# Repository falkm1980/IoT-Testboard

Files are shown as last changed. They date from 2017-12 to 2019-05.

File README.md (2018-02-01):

# IoT-Testboard
IoT-Testboard for Raspberry pi and ESP8266

In order to get the IoT-Evaluation board running you need a recent image of Raspian-Linux.
https://www.raspberrypi.org/downloads/raspbian/

Furthermore you need to install a few more libraries.

## Wiring Pi
git clone https://github.com/WiringPi/WiringPi

./build

## Adafruit_Python GPIO Library
git clone https://github.com/adafruit/Adafruit_Python_GPIO

## Adafruit ILI9341 Display Library
git clone https://github.com/adafruit/Adafruit_Python_ILI9341

## RC-Switch (Radio outlets)
git clone https://github.com/r10r/rcswitch-pi

make

## DHT 11/22 Temp/Humidity sensor
git clone https://github.com/adafruit/Adafruit_Python_DHT

## NeoPixel WS2812:
sudo apt-get update

sudo apt-get install icons

sudo apt-get install scons

sudo apt-get install swig

sudo apt-get install build-essential python-dev unzip wget 

wget https://github.com/jgarff/rpi_ws281x/archive/master.zip && unzip master.zip && cd rpi_ws281x-master && sudo scons && cd python && 
sudo python setup.py install

## optional Div. Python libs:
sudo pip install pytz (for timezone calculation)

## Optional: Node.JS latest version
sudo wget -O - https://raw.githubusercontent.com/audstanley/NodeJs-Raspberry-Pi/master/Install-Node.sh | sudo bash;
node -v;

## Mqtt ##
Install MQTT Broker: sudo apt-get install moquitto

Install MQTT Pyhon lib: pip install paho-mqtt

see also: https://www.dinotools.de/2015/04/12/mqtt-mit-python-nutzen/

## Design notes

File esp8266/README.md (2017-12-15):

# ESP8266 Module on the board

## Installation Prerequisites
Before we can start using the ESP8266 Module we need to install some prerequisites.
check out: https://learn.adafruit.com/building-and-running-micropython-on-the-esp8266/flash-firmware

or alternatively:
http://docs.micropython.org/en/latest/esp8266/esp8266/tutorial/intro.html#deploying-the-firmware

This python file is necessary to update the MicroPython firmare installed on the module.

latest firmware can be found here:
http://micropython.org/download

## Communication with the module
in order to be able to establish a connection between the ESP8266 module and the Raspberry we need a USB cable
to connect the 2 devices.

once connected you should see a new device on the Raspberry  "/dev/ttyUSB0". ttyUSB0 can also have another name.
ttyUSB0 is a vitual serial device

Install command "screen" on the Raspberry to open up a serial terminal
sudo apt-get install screen

ince installed you can use the following command:
screen /dev/ttyUSB0 115200

now you should have a terminal open that can "talk" to the ESP8266 module.
Type: 1+1 or print ("Hello world") and see what happens.

Post request with MicroPython:
https://techtutorialsx.com/2017/06/18/esp32-esp8266-micropython-http-post-requests/

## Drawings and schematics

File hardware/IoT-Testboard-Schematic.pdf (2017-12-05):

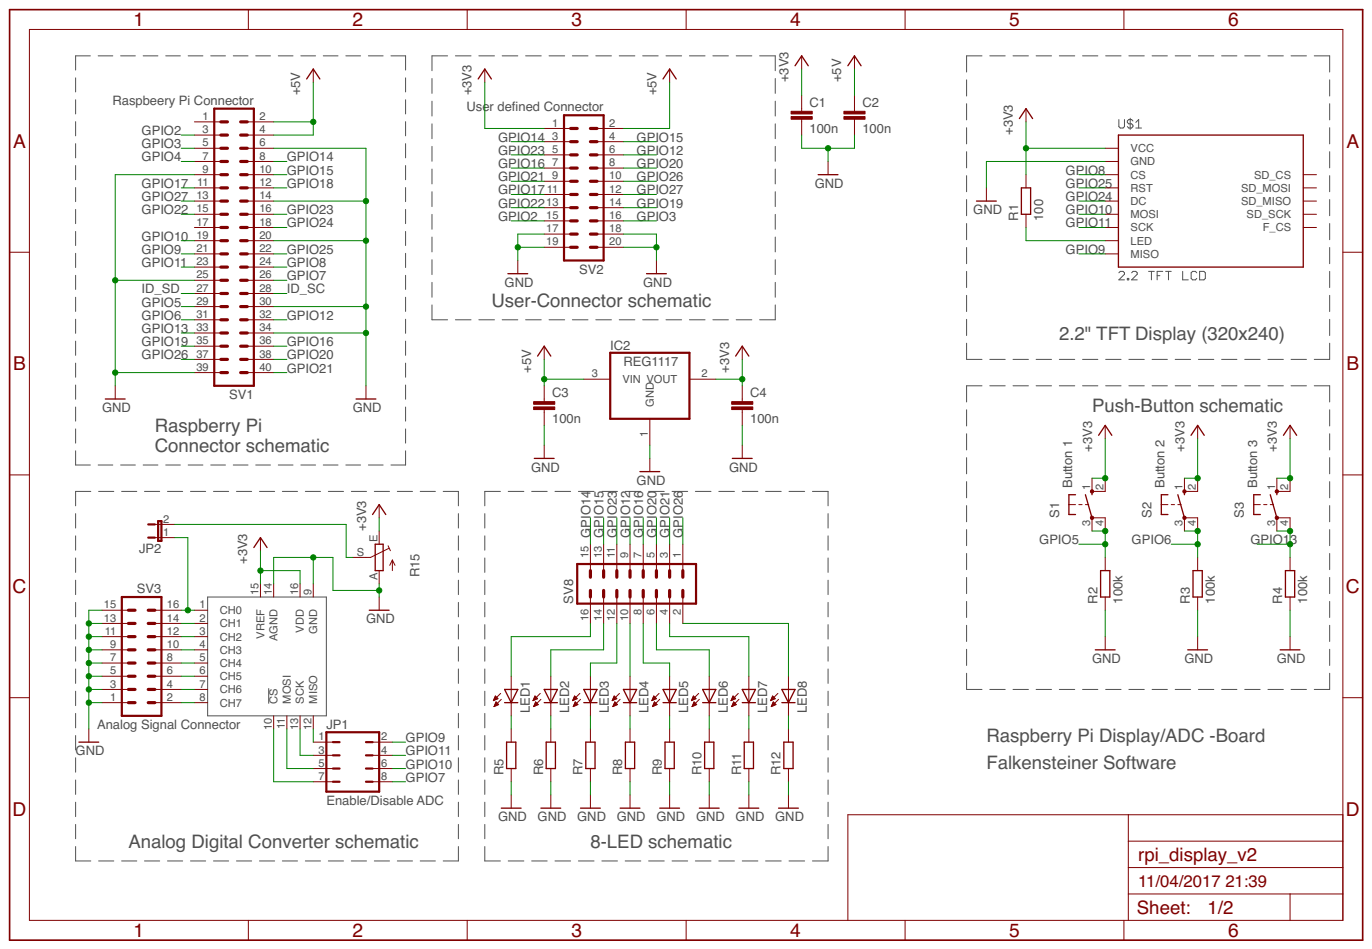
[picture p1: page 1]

Analog Signal Connector GND

Raspberry Pi Display/ADC -Board
Falkensteiner Software

GND GND GND GND

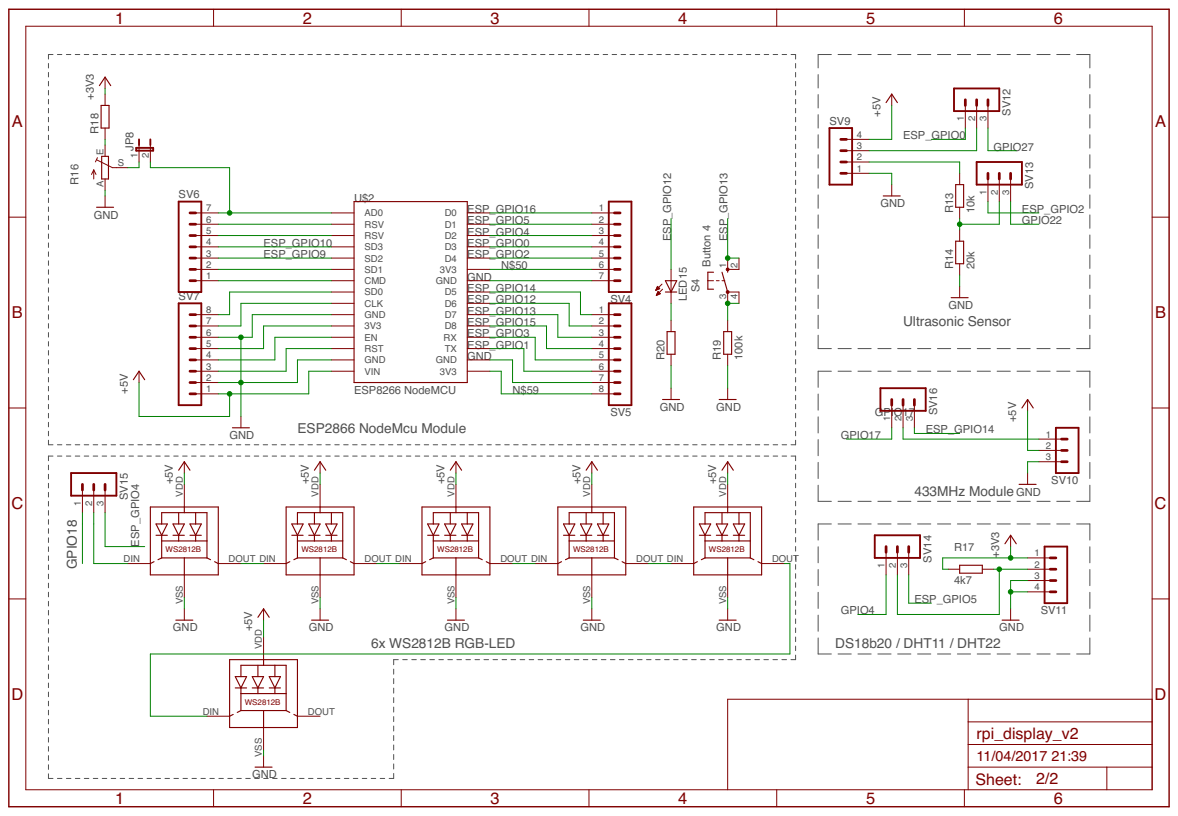
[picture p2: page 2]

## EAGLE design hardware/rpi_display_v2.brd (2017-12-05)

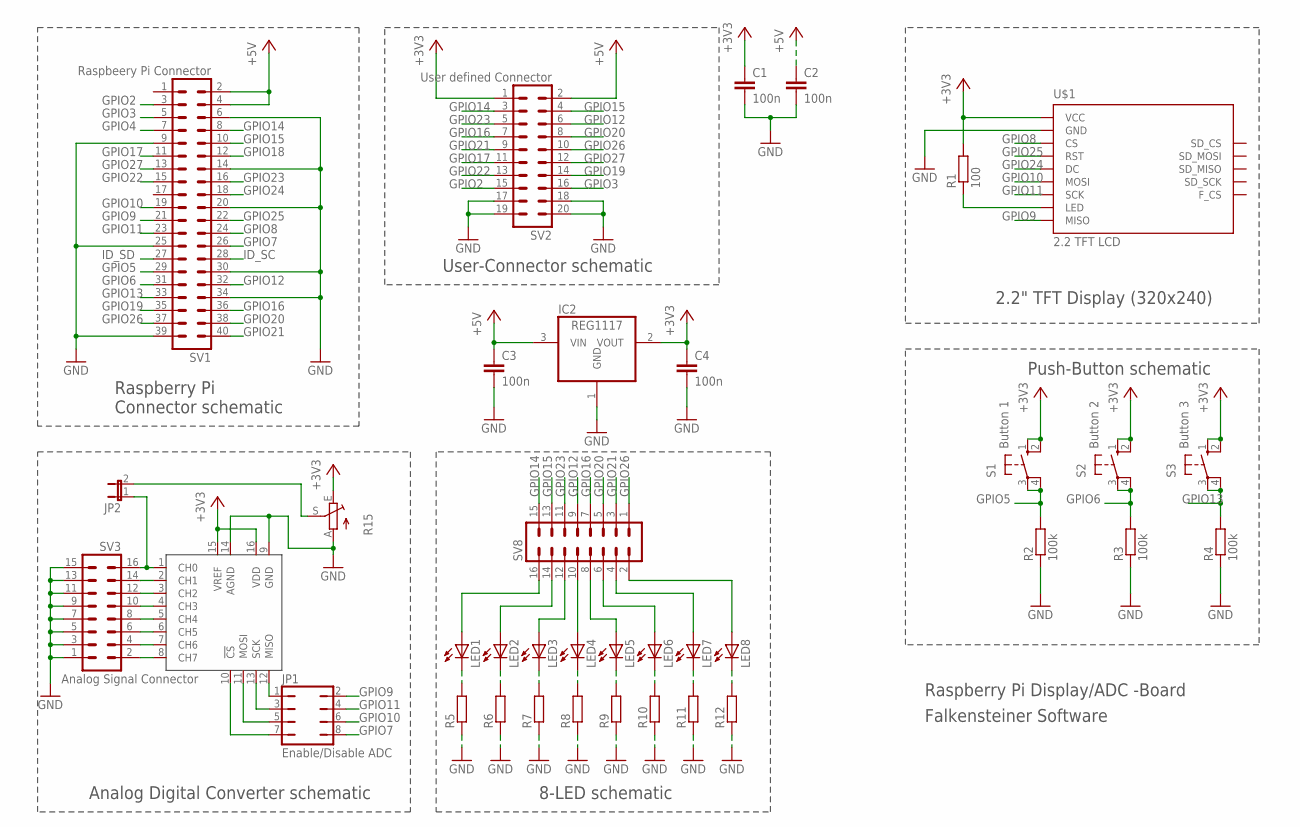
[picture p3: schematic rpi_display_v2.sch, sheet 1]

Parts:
C1, C2, C3, C4: 100n; C1206
IC1: MCP3008P; DIL16
IC2: REG1117; SOT223
JP1: Enable/Disable ADC; JP4Q
JP2: JP1E; JP1
LED1, LED2, LED3, LED4, LED5, LED6, LED7, LED8: LEDSML1206; SML1206
R1: 100; R1206
R2, R3, R4: 100k; R1206
R5, R6, R7, R8, R9, R10, R11, R12: R-EU_R1206; R1206
R15: TRIM_EU-CA6V; CA6V
S1: Button 1; B3F-10XX
S2: Button 2; B3F-10XX
S3: Button 3; B3F-10XX
SV1: Raspbeery Pi Connector; MA20-2
SV2: User defined Connector; MA10-2
SV3: Analog Signal Connector; MA08-2
SV8: MA08-2
U$1: 2.2_TFT_LCD

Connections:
+3V3: C1.1, C4.1, IC1.15 (VREF), IC1.16 (VDD), IC2.2 (VOUT), R1.2, R15.E, S1.1 (S), S1.2 (S1), S2.1 (S), S2.2 (S1), S3.1 (S), S3.2 (S1), SV2.1, U$1.VCC; also elsewhere on the board
+5V: C2.1, C3.1, IC2.3 (VIN), SV1.2, SV1.4, SV2.2; also elsewhere on the board
GND: C1.2, C2.2, C3.2, C4.2, IC1.9 (GND), IC1.14 (AGND), IC2.1 (GND), R2.1, R3.1, R4.1, R5.1, R6.1, R7.1, R8.1, R9.1, R10.1, R11.1, R12.1, R15.A, SV1.6, SV1.9, SV1.14, SV1.20, SV1.25, SV1.30, SV1.34, SV1.39, SV2.17, SV2.18, SV2.19, SV2.20, SV3.1, SV3.3, SV3.5, SV3.7, SV3.9, SV3.11, SV3.13, SV3.15, U$1.GND; also elsewhere on the board
GPIO2: SV1.3, SV2.15
GPIO3: SV1.5, SV2.16
GPIO4: SV1.7; also elsewhere on the board
GPIO5: R2.2, S1.3, S1.4 (P1), SV1.29
GPIO6: R3.2, S2.3, S2.4 (P1), SV1.31
GPIO7: JP1.8, SV1.26
GPIO8: SV1.24, U$1.CS
GPIO9: JP1.2, SV1.21, U$1.MISO
GPIO10: JP1.6, SV1.19, U$1.MOSI
GPIO11: JP1.4, SV1.23, U$1.SCK
GPIO12: SV1.32, SV2.6, SV8.9
GPIO13: R4.2, S3.3, S3.4 (P1), SV1.33
GPIO14: SV1.8, SV2.3, SV8.15
GPIO15: SV1.10, SV2.4, SV8.13
GPIO16: SV1.36, SV2.7, SV8.7
GPIO17: SV1.11, SV2.11; also elsewhere on the board
GPIO18: SV1.12; also elsewhere on the board
GPIO19: SV1.35, SV2.14
GPIO20: SV1.38, SV2.8, SV8.5
GPIO21: SV1.40, SV2.9, SV8.3
GPIO22: SV1.15, SV2.13; also elsewhere on the board
GPIO23: SV1.16, SV2.5, SV8.11
GPIO24: SV1.18, U$1.DC
GPIO25: SV1.22, U$1.RST
GPIO26: SV1.37, SV2.10, SV8.1
GPIO27: SV1.13, SV2.12; also elsewhere on the board
ID_SC: SV1.28
ID_SD: SV1.27
unnamed: R1.1, U$1.LED
unnamed: IC1.12 (MISO), JP1.1
unnamed: IC1.13 (SCK), JP1.3
unnamed: IC1.11 (MOSI), JP1.5
unnamed: IC1.10 (!CS), JP1.7
unnamed: IC1.1 (CH0), JP2.1, SV3.16
unnamed: IC1.2 (CH1), SV3.14
unnamed: IC1.3 (CH2), SV3.12
unnamed: IC1.4 (CH3), SV3.10
unnamed: IC1.5 (CH4), SV3.8
unnamed: IC1.6 (CH5), SV3.6
unnamed: IC1.7 (CH6), SV3.4
unnamed: IC1.8 (CH7), SV3.2
unnamed: LED1.A, SV8.16
unnamed: LED1.C, R5.2
unnamed: LED2.A, SV8.14
unnamed: LED2.C, R6.2
unnamed: LED3.A, SV8.12
unnamed: LED3.C, R7.2
unnamed: LED4.A, SV8.10
unnamed: LED4.C, R8.2
unnamed: LED5.A, SV8.8
unnamed: LED5.C, R9.2
unnamed: LED6.A, SV8.6
unnamed: LED6.C, R10.2
unnamed: LED7.A, SV8.4
unnamed: LED7.C, R11.2
unnamed: LED8.A, SV8.2
unnamed: LED8.C, R12.2
unnamed: JP2.2, R15.S

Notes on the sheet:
Raspberry Pi Display/ADC -Board
Falkensteiner Software
Push-Button schematic
User-Connector schematic
Raspberry Pi Connector schematic
Analog Digital Converter schematic
8-LED schematic
2.2" TFT Display (320x240)

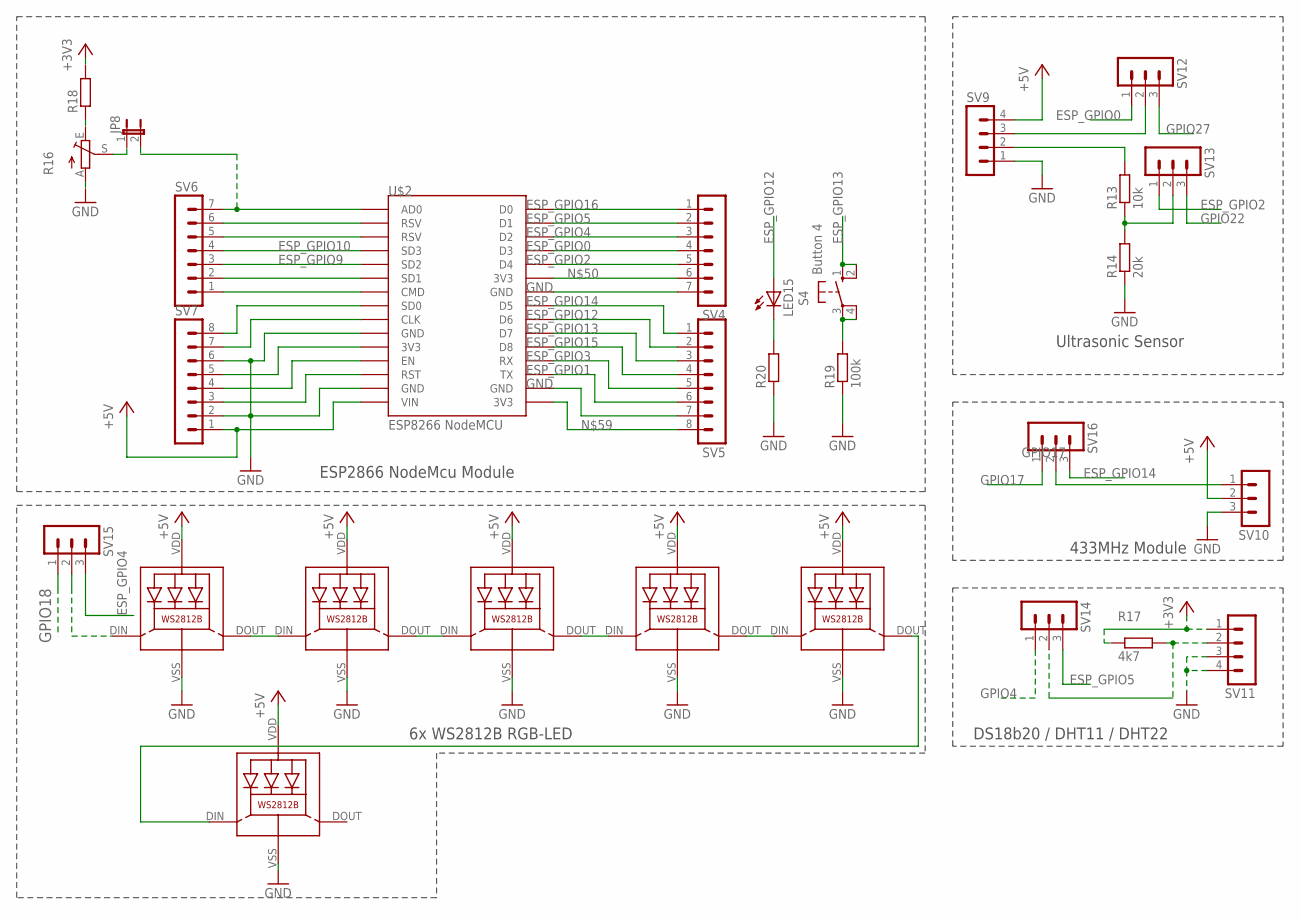
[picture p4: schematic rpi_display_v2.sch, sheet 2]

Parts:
JP8: JP1E; JP1
LED9, LED10, LED11, LED12, LED13, LED14: WS2812B
LED15: LEDSML1206; SML1206
R13: 10k; R1206
R14: 20k; R1206
R16: TRIM_EU-CA6V; CA6V
R17: 4k7; R1206
R18, R20: R-EU_R1206; R1206
R19: 100k; R1206
S4: Button 4; B3F-10XX
SV4, SV6: MA07-1
SV5, SV7: MA08-1
SV9, SV11: MA04-1
SV10, SV12, SV13, SV14, SV15, SV16: MA03-1
U$2: ESP8266 NodeMCU; ESP12E_DEVKIT

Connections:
+3V3: R17.1, R18.2, SV11.1; also elsewhere on the board
+5V: LED9.VDD, LED10.VDD, LED11.VDD, LED12.VDD, LED13.VDD, LED14.VDD, SV7.1, SV9.4, SV10.2, U$2.VIN; also elsewhere on the board
ESP_GPIO0: SV4.4, SV12.1, U$2.D3
ESP_GPIO1: SV5.6, U$2.TX
ESP_GPIO2: SV4.5, SV13.1, U$2.D4
ESP_GPIO3: SV5.5, U$2.RX
ESP_GPIO4: SV4.3, SV15.3, U$2.D2
ESP_GPIO5: SV4.2, SV14.3, U$2.D1
ESP_GPIO9: SV6.3, U$2.SD2
ESP_GPIO10: SV6.4, U$2.SD3
ESP_GPIO12: LED15.A, SV5.2, U$2.D6
ESP_GPIO13: S4.1 (S), S4.2 (S1), SV5.3, U$2.D7
ESP_GPIO14: SV5.1, SV16.3, U$2.D5
ESP_GPIO15: SV5.4, U$2.D8
ESP_GPIO16: SV4.1, U$2.D0
GND: LED9.VSS (GND), LED10.VSS (GND), LED11.VSS (GND), LED12.VSS (GND), LED13.VSS (GND), LED14.VSS (GND), R14.1, R16.A, R19.1, R20.1, SV4.7, SV5.7, SV7.2, SV7.6, SV9.1, SV10.3, SV11.3, SV11.4, U$2.GND@0 (GND), U$2.GND@1 (GND), U$2.GND@2 (GND), U$2.GND@3 (GND); also elsewhere on the board
GPIO4: SV14.1; also elsewhere on the board
GPIO17: SV16.1; also elsewhere on the board
GPIO18: SV15.1; also elsewhere on the board
GPIO22: SV13.3; also elsewhere on the board
GPIO27: SV12.3; also elsewhere on the board
unnamed: JP8.2, SV6.7, U$2.AD0
unnamed: SV6.6, U$2.RSV@0 (RSV)
unnamed: SV6.5, U$2.RSV@1 (RSV)
unnamed: LED15.C, R20.2
unnamed: R19.2, S4.3, S4.4 (P1)
unnamed: SV6.2, U$2.SD1
unnamed: SV6.1, U$2.CMD
unnamed: SV7.8, U$2.SD0
unnamed: SV7.7, U$2.CLK
unnamed: LED13.DOUT (DO), LED14.DIN (DI)
unnamed: SV7.5, U$2.3V3@0 (3V3)
unnamed: SV7.4, U$2.EN
unnamed: SV7.3, U$2.RST
unnamed: LED9.DOUT (DO), LED10.DIN (DI)
unnamed: LED10.DOUT (DO), LED11.DIN (DI)
unnamed: SV4.6, U$2.3V3@1 (3V3)
unnamed: SV5.8, U$2.3V3@2 (3V3)
unnamed: LED11.DOUT (DO), LED12.DIN (DI)
unnamed: LED12.DOUT (DO), LED13.DIN (DI)
unnamed: R13.1, R14.2, SV13.2
unnamed: R13.2, SV9.2
unnamed: SV9.3, SV12.2
unnamed: SV10.1, SV16.2
unnamed: LED9.DIN (DI), SV15.2
unnamed: R17.2, SV11.2, SV14.2
unnamed: R16.E, R18.1
unnamed: JP8.1, R16.S

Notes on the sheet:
Ultrasonic Sensor
433MHz Module
DS18b20 / DHT11 / DHT22
6x WS2812B RGB-LED
ESP2866 NodeMcu Module

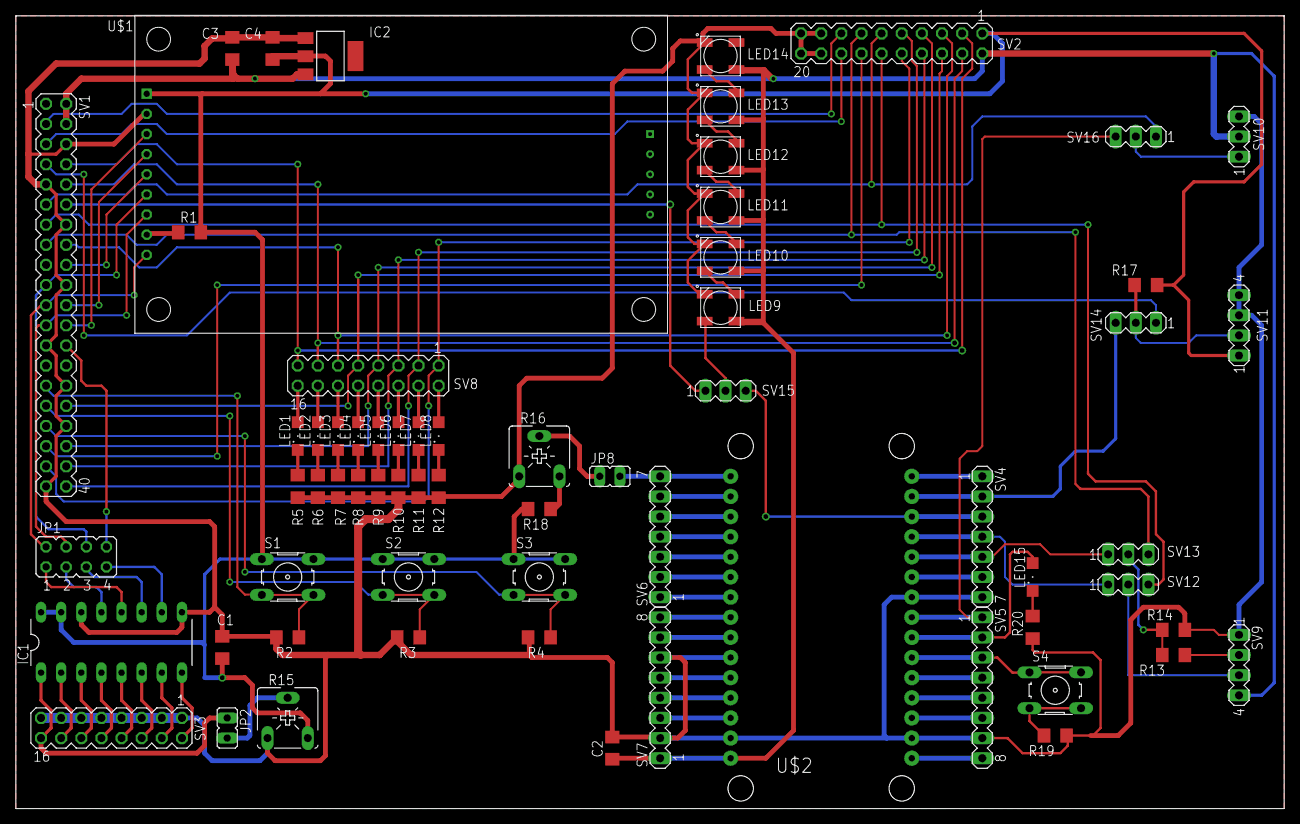
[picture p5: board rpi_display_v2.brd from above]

Board: 2 copper layers, 160.0 x 100.0 mm, 66 parts (0 on the bottom side), 99 nets.

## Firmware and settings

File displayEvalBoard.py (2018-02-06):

#!/usr/bin/python

from ili9341AdafruitWrapper import ili9341AdafruitWrapper as display
import displayCanvas
import time
import datetime, pytz
from PIL import Image, ImageDraw, ImageFont

import dhtSensorEvalBoard as DHT
import distanceEvalBoard as ultrasonicSensor
import mcp3008 as ADC

fontDigital = ImageFont.truetype('font/digital-7.ttf', 35)
font1 = ImageFont.truetype('font/atwriter.ttf', 30)
fontSanchez = ImageFont.truetype('font/Sanchezregular.otf', 20)

MARGIN_Y = 5

def GetDateTimeByTimezone(tz = "Europe/Vienna"):
    def GetDayOfWeek(i):
        if i == 0:
            return "Montag"
        elif i == 1:
            return "Dienstag"
        elif i == 2:
            return "Mittwoch"
        elif i == 3:
            return "Donnerstag"
        elif i == 4:
            return "Freitag"
        elif i == 5:
            return "Samstag"
        elif i == 6:
            return "Sonntag"
        else:
            return "unknown day"
            
    now =  datetime.datetime.now(pytz.timezone(tz))
    dateString = "{0}, {1}.{2}.{3}".format(GetDayOfWeek(now.weekday()), now.day, now.month, now.year)
    timeString = "{0:02}:{1:02}".format(now.hour, now.minute)
    return (dateString, timeString)

def Test():
	tft = display((320,240))
	canvas = displayCanvas.DisplayCanvas(tft)

	ultrasonicSensor.Setup()
	ADC.Open()

	

	while True:
		with(canvas):
			humidity, temperature = DHT.GetTempAndHumidity(11, 4)
	#		humidity=34.3
	#		temperature=27.5
			dateTime = GetDateTimeByTimezone()
			dist = ultrasonicSensor.MeasureDistance()
			sDistance = 'Distance: {0:0.1f} cm'.format(dist)
			w = ADC.GetVoltageValue(0)

			sz = canvas.DrawTextCenter(10, "IoT-EvalBoard", font=font1, fill=(0,255,0))
			sz = canvas.DrawTextCenter(10+sz[1]+5, dateTime[1], font=fontDigital, fill=(0,255,0))
			sz = canvas.DrawLineCenter(sz[2] + MARGIN_Y, 200, fill=(255,0,0))
			s = 'Temp={0:0.1f}  Humidity={1:0.1f}%'.format(temperature, humidity)
			sz = canvas.DrawTextCenter(sz[2]+MARGIN_Y, s, font=fontSanchez, fill=(255,165,0))
			sz = canvas.DrawTextCenter(sz[2]+MARGIN_Y, sDistance, font=fontSanchez, fill=(255,165,0))

			sADC = 'CH0: {0:0.2f} V'.format(w)
			sz = canvas.DrawTextCenter(sz[2]+MARGIN_Y, sADC, font=fontSanchez, fill=(255,165,0))

		time.sleep(10)

def Test2():
	tft = display((320,240))
	canvas = displayCanvas.DisplayCanvas(tft)

#	ultrasonicSensor.Setup()
#	ADC.Open()

	logo = Image.open("logo.png");

	lastupdate = datetime.datetime.now()

	humidity, temperature = DHT.GetTempAndHumidity(11, 4)
	first = True

	while True:
		with(canvas):
			now = datetime.datetime.now()
			diff = now - lastupdate
			if diff.seconds > 120 or first == True:
				lastupdate = datetime.datetime.now()
				humidity, temperature = DHT.GetTempAndHumidity(11, 4)
				first = False
				print ("update of temp:" + str(diff.seconds))

			dateTime = GetDateTimeByTimezone()
			canvas.DrawBitmap((10,10), logo)
			sz = canvas.DrawText(65, 15, "HTL Saalfelden", font=font1, fill=(0,255,255))
			sz = canvas.DrawTextCenter(20 + sz[2], "Tag der offenen Tuer", font=font1, fill=(0,255,0))
			sz = canvas.DrawTextCenter(10+sz[2]+5, dateTime[0], font=fontDigital, fill=(0,255,0))
			sz = canvas.DrawTextCenter(10+sz[2]+5, dateTime[1], font=fontDigital, fill=(0,255,0))
			s = 'Temp={0:0.1f}  Feuchtigkeit={1:0.1f}%'.format(temperature, humidity)
			sz = canvas.DrawTextCenter(sz[2]+MARGIN_Y, s, font=fontSanchez, fill=(255,165,0))
			canvas.DrawLineCenter(65, 300, fill=(255,0,0))
		time.sleep(1)


if __name__ == "__main__":
	Test()

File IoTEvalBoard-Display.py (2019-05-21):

#!/usr/bin/python

import time
import RPi.GPIO as GPIO
import ws2812bEvalBoard as ws2812
import displayEvalBoard as displayEvalBoard
import dhtSensorEvalBoard as DHT

import mcp3008 as ADC

 
ledOutput = [14,15,23,12,16,20,21,26]

btnInput = [5,6,13]

ledStrip = None

def Btn1_Click(channel):
	global ledStrip
	GPIO.output(ledOutput[0], GPIO.HIGH)
	time.sleep(0.5)
	GPIO.output(ledOutput[0], GPIO.LOW)
	for i in range(5):
		ws2812.Test(ledStrip)

	ws2812.LedOff(ledStrip)

def Btn2_Click(channel):
	GPIO.output(ledOutput[1], GPIO.HIGH)
	time.sleep(0.5)
	GPIO.output(ledOutput[1], GPIO.LOW)

def Btn3_Click(channel):
	GPIO.output(ledOutput[2], GPIO.HIGH)
	time.sleep(0.5)
	GPIO.output(ledOutput[2], GPIO.LOW)

def Setup():
	global ledStrip

	GPIO.setmode(GPIO.BCM)

	GPIO.setup(ledOutput, GPIO.OUT)
	GPIO.setup(btnInput, GPIO.IN)

	GPIO.add_event_detect(btnInput[0], GPIO.RISING, callback=Btn1_Click)
	GPIO.add_event_detect(btnInput[1], GPIO.RISING, callback=Btn2_Click)
	GPIO.add_event_detect(btnInput[2], GPIO.RISING, callback=Btn3_Click)

	ledStrip = ws2812.MakeStrip()

def CleanUp():
	GPIO.cleanup()



def main():
	print ("Main...")

#	displayEvalBoard.Test()

	GPIO.output(ledOutput, GPIO.HIGH)
	time.sleep(2)
	GPIO.output(ledOutput, GPIO.LOW)

	displayEvalBoard.Test()

if __name__ == "__main__":
	Setup()

	try:
		main()
	except KeyboardInterrupt:
		CleanUp()
		print ("bye-bye....")

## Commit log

2017-12-05 added EagleFiles and Schematic PDF
    [rpi_display_v2.brd, rpi_display_v2.sch]
2018-02-02 added max_speed_hz
    added max_speed_hz in Open function. Otherwise the ADC doesn't work with the latest raspbian image
    [mcp3008.py]
2018-02-06 print update beacuse of Python3
2018-02-06 Python3 Distance Sensor file
2018-02-06 DispOnlyTest update without DHT1 sensor
